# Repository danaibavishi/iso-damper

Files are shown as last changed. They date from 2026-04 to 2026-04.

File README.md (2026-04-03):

**3D Printable · PETG · Open Source · Compliant Mechanism**

# Vibration Isolation Damper for Bookshelf Speakers

Stop your speaker from vibrating your shelf. Built around a real BYU orthoplanar spring — engineered from scratch in Python, iterated through TinkerCAD, tuned for the Sonos Era 100.

| pucks to print | spring scale | deflection | filament cost | design phases |
| --- | --- | --- | --- | --- |
| 3× | 0.40× | 0.63mm | ~$2 | 4 |

## Why does this exist?

The Sonos Era 100 sits directly on your shelf. At volume, cabinet vibrations travel through the shelf into the wall — and back into the bass as muddy resonance. IsoAcoustics pads fix this but cost $50–100. This builds the same thing for the price of a coffee's worth of PETG.

> The key insight: Vibration travels through rigid contact. Break that path with a compliant spring and it has nowhere to go — that's what an orthoplanar spring does.

## The final design

### Print this file — 3 copies
`04_compliant_puck/compliant_puck_FINAL.stl`
*One monolithic piece. No assembly, no hardware. Print 3, place in a triangle under the speaker.*

**Outer diameter:** 57.9 mm  
**Total height:** 24.5 mm  
**Spring arms:** 3× BYU radial legs — 2.0mm wide × 1.52mm thick  
**Arm angles:** 38° / 158° / 278° — matched from BYU STL  
**Deflection:** 0.63mm under 733g load  
**Max stress:** 45 MPa — just under PETG yield (~50 MPa)  
**Pedestal:** 10mm hollow cylinder + 7mm hemisphere dome base  
**Top surface:** 1mm flat solid disc  

*Figure 1 — Compliant puck cross-section · monolithic PETG print*

## Finding the right scale

The BYU spring is 144.8mm across — too large for 3 to fit under the speaker. Scale it down too far and the arms snap. The constraint: 0.2mm layers means arms need at least 1.2mm thickness, setting the minimum spring size.

*Figure 2 — BYU spring anatomy and scale selection*

## How we got here

Four phases, multiple iterations each — every version fixing something the last one got wrong.

1. **Isolation pad** — Simple nub-footed pads. Added BYU spring mechanism. Two versions before realising the spring needed to be structural, not decorative.
2. **Two-piece stand** — Inspired by iRetroLab crystal stands. Tapered pedestal + oval cylinder, spring sandwiched between. Three iterations fixed the connection geometry.
3. **Unified puck** — One monolithic print. Ten iterations: tapered → hollow → domed pedestal. Spring tuned to 0.40× BYU scale.
4. **Tray** — Six iterations. Final: 2mm oval plate (120×130.5mm), 3 pucks embedded below, 1mm raised border to register the speaker.

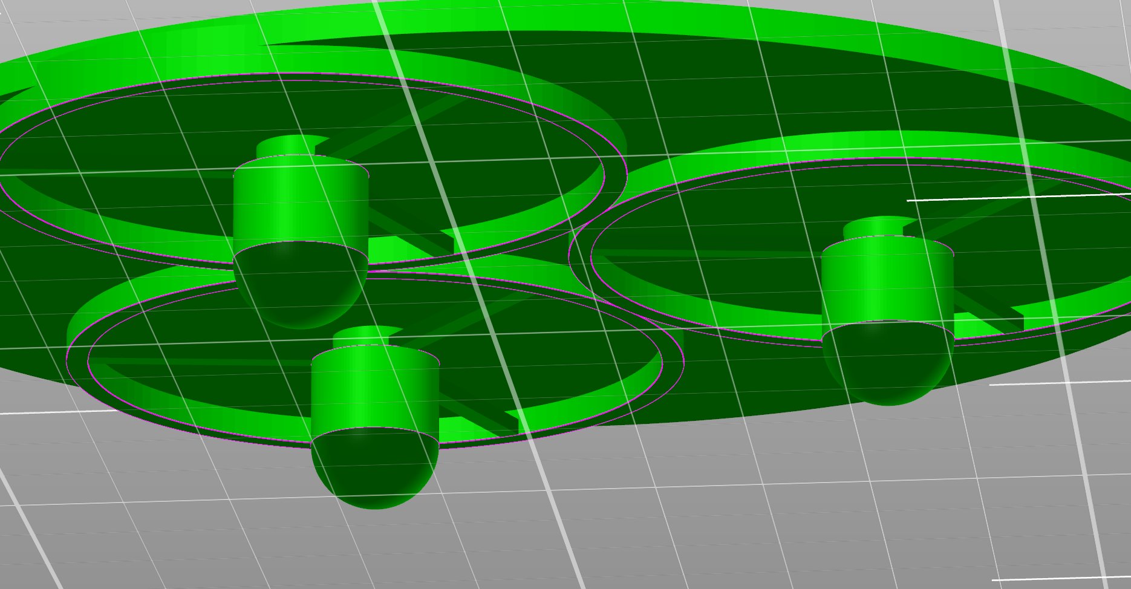
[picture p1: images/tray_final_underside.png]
Final tray — underside showing 3 pucks with dome feet


## The engineering

Each arm is a fixed-guided beam — both ends locked, loaded vertically. Two equations govern everything:

```
δ = F·L³ / (12·E·I) // deflection under load
σ = 6·F·L / (w·t²) // max stress at fixed ends
```

At 0.40× with PETG (E = 1700 MPa): each arm carries 2.4N, deflects 0.63mm — just under the 50 MPa yield point.

> Why 0.40× and not smaller? Below 0.35× the arms exceed PETG yield — permanent deformation. 0.40× is the minimum viable scale at standard 0.2mm layer settings.

## What's in the repo

```
01_concept/           BYU spring STL + anatomy diagram
02_isolation_pad/     nub pad → compliant isolator iterations
03_stand_two_piece/   pedestal + cylinder tray · SCADs
04_compliant_puck/
  compliant_puck_FINAL.stl  ← print this × 3
  iterations/                  v1–v7 intermediate designs
05_tray/
  tray_FINAL.stl              ← oval plate + 3 embedded pucks
  iterations/                  tray v1–v5 exploration
docs/                 engineering_notes.md
images/               all TinkerCAD + slicer screenshots
```

## References

- **BYU Compliant Mechanisms Research Group** — Source of the orthoplanar spring design and STL files
- **Parise, Howell, Magleby** — *Ortho-Planar Linear-Motion Springs*, Mechanism and Machine Theory, Vol. 36, 2001
- **US Patent 6,983,924** — Compliant Ortho-Planar Linear Motion Spring
- **IsoAcoustics** — Commercial isolation reference — same principle, $50–100 price point
- **iRetroLab crystal stand** — Aesthetic inspiration — visible spring mechanism

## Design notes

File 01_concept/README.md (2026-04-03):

**Concept · BYU Research**

# 01 — The Orthoplanar Spring

Everything starts here. A flat spring that deflects vertically — manufactured as a single piece with no assembly required.

## What is an orthoplanar spring?

An orthoplanar spring is a flat, planar mechanism that deflects out of plane (vertically) under load. Unlike a coil spring, it doesn't rotate as it deflects, can be printed as a single flat piece, and has predictable, tuneable stiffness based on arm geometry.

> BYU source: This design comes from the Compliant Mechanisms Research Group at Brigham Young University, led by Prof. Larry Howell. Their STL is the foundation for everything in this project.

*BYU orthoplanar spring — top-down anatomy · 144.78mm diameter*

## Geometry (reverse-engineered from STL)

**Outer diameter:** 144.78 mm  
**Height:** 3.81 mm  
**Centre hub radius:** ~10 mm  
**Outer ring:** r 64–72.4mm (8.4mm wide)  
**Number of arms:** 3 straight radial beams  
**Arm angular positions:** 38° / 158° / 278°  
**Arm width at r=40mm:** ~5 mm  
**Arm region:** r 21.9mm to 58.5mm  

> Why 38° offset? The arms are at 38°/158°/278° — not 0°/120°/240°. This offset prevents alignment with the primary loading axes, distributing stress more evenly across all three arms.

## How it works

The centre hub is the fixed ground — it connects to the pedestal which sits on the shelf. The outer ring is the floating platform — it connects to the cylinder that holds the speaker. The three arms bridge between them, flexing vertically under load.

```
Load applied to outer ring → arms flex in Z direction
Outer ring displaces ±0.63mm relative to fixed hub
Vibration energy absorbed → not transmitted to shelf
```

## Files in this folder

byu_orthoplanar_spring.stl
← original BYU geometry, used as reference throughout

The original spring is 144.8mm in diameter. We scale it to 0.40× (57.9mm OD) for use in the puck — see 04_compliant_puck for full scale analysis.

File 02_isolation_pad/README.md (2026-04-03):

**Phase 1 · First Iteration**

# 02 — Isolation Pad

The first attempt. Simple pads that evolved into proper spring mechanisms — before we realised the spring needed to be structural, not decorative.

## The idea

Start simple: flat pads with small nub feet to create a standoff between speaker and shelf. Minimal contact area = less vibration transmission. Then add a spring inside to get real compliance.

Early pad iteration — tapered pedestal form in TinkerCAD

## Iterations

### v1 — Nub pad

Flat rectangular pad (122×132.5mm). Four tapered nubs on the underside create a standoff. No spring mechanism — pure decoupling through minimal contact area.

> Problem: Nubs reduce contact area but don't provide compliance. The speaker still transmits vibration directly through the rigid pad body.

### v2 — Compliant isolator v1

Added an orthoplanar spring mechanism inside the pad. Three curved arms connecting a centre hub to an outer ring.

> Problem: The arm geometry was disconnected — inner plate floated with no structural connection to the outer ring.

### v3 — Compliant isolator v2

Fixed the arm connections. Hub properly bridges to outer ring. This version works mechanically but the flat disc form factor doesn't provide enough vertical clearance for spring travel.

> Key learning: A flat pad is too low-profile. The spring needs height — the deflection path requires vertical clearance below the speaker. This realisation drove the two-piece stand concept.

## Files in this folder

isolation_pad_v1.stl
nub pad — no spring
isolation_pad_v1.scad
OpenSCAD source
compliant_isolator_v2.stl
fixed spring geometry

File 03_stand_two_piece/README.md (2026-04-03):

**Phase 2 · Press-fit Assembly**

# 03 — Two-Piece Stand

Inspired by iRetroLab crystal glass stands — a visible spring mechanism sandwiched between two press-fit pieces. Three pedestal iterations to get the geometry right.

| pieces | pedestal versions | press-fit clearance |
| --- | --- | --- |
| --- | --- | --- |
| 2 | 3 | 0.2mm |

## Assembly concept

Piece 1 (pedestal) press-fits into the spring centre hub from below. Piece 2 (cylinder + tray) grips the spring outer ring from above. The spring floats between them — no glue, no hardware.

Two-piece stand — disconnected in TinkerCAD showing the separate components

> Design reference: iRetroLab crystal stands use a similar principle — a transparent column with visible spring mechanism, aluminium tray on top, conical base below.

## Pedestal iterations

- **[v1 — rejected]** — **Hollow tapered cone + base ring** — Centre hub disconnected from cone walls — visible gap.
- **[v2 — better]** — **Solid top cap added** — Bridges walls to hub. Base ring still present.
- **[v3 — final]** — **Base ring removed** — Cone sits directly on shelf. Clean minimal form.

### Cylinder tray — 3 versions

- **[v1 — too deep]** — **18mm collar** — Much longer than spring height — wastes material.
- **[v2 — better]** — **10mm collar** — Matched to spring height + small overlap.
- **[v3 — final]** — **Spring height + 2mm** — 0.2mm press-fit clearance. Tight and clean.

## Why we moved on

The oval speaker footprint vs circular spring created a shape mismatch. Making the spring oval requires non-uniform scaling (82.9% X, 90.1% Y) which distorts the arm geometry unevenly — different stiffness on each arm, uneven load distribution.

> Solution: Collapse both pieces into a single monolithic print with the spring geometry built in at the correct scale from the start — no oval distortion needed.

## Files in this folder

pedestal_FINAL.stl
piece 1 — tapered cone, final version
cylinder_tray_FINAL.stl
piece 2 — oval cylinder + tray
piece1_pedestal.scad
OpenSCAD source for pedestal
piece2_cylinder_tray.scad
OpenSCAD source for cylinder tray

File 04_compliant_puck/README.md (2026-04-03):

**Phase 04 · Final Design · 7 Iterations · Print 3x**

# Compliant Puck

The final design. One monolithic print — pedestal, spring, and cylinder in a single piece. Seven iterations refined the geometry until every element was proportional, printable, and functional.

### Print this file — 3 copies
`compliant_puck_FINAL.stl`
*One piece. No assembly, no hardware. Print 3, place in a triangle under the speaker.*

## Final specifications

**Outer diameter:** 57.9 mm  
**Total height:** 24.5 mm  
**Spring arms:** 3x BYU radial — 2.0mm wide x 1.52mm thick at 38/158/278 deg  
**Deflection:** 0.63mm under 733g  
**Max stress:** 45 MPa — PETG yield ~50 MPa  
**Pedestal:** 10mm hollow cylinder + 7mm hemisphere dome  

*Figure 4.1 — Final puck cross-section*

## The iteration journey

From wide-cone tapered base to clean cylinder-plus-dome. Each screenshot marks a decision point.

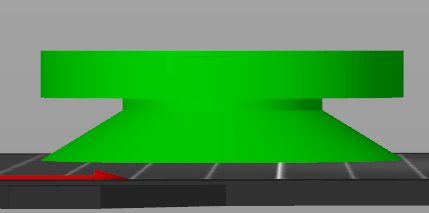
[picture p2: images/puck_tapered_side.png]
Tapered pedestal


v1-v3 — tapered cone — too wide

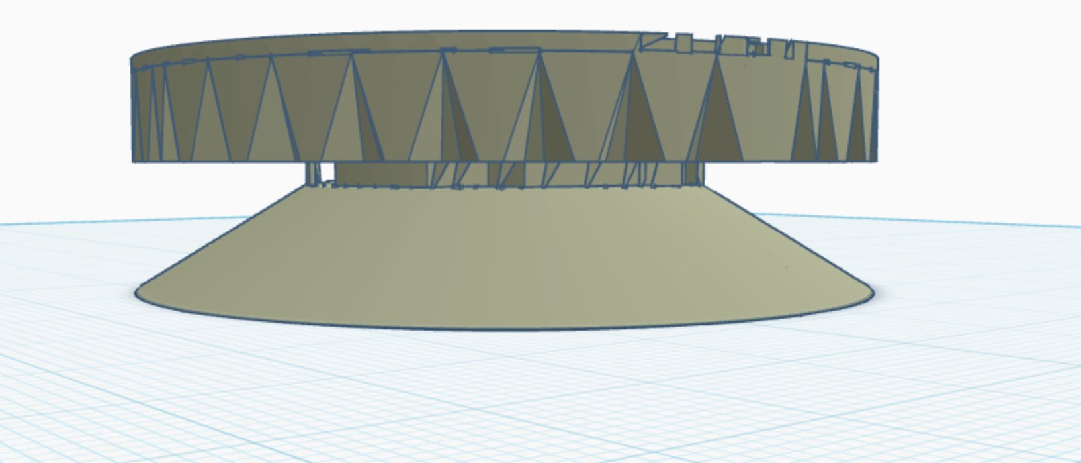
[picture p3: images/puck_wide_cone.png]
Wide cone version


v4 — full-size BYU spring — too large

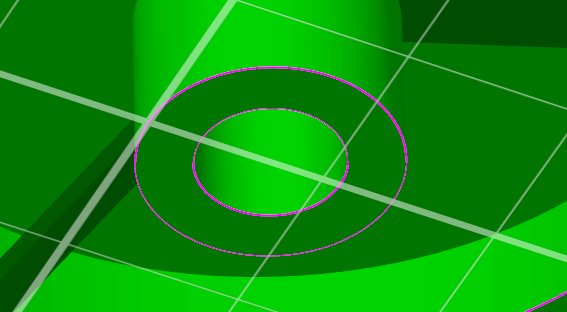
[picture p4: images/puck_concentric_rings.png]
Concentric rings top view


Breakthrough — top-down concentric rings confirmed correct spring geometry at 0.40x scale

> This view locked the design. Seeing hub, arm region, and outer ring clearly defined in one view confirmed the spring would work. From here the only remaining question was the pedestal shape.

## Full iteration log

| Version | Change | Outcome |
| --- | --- | --- |
| v1_initial | Curved spiral arms | Wrong arm style — not BYU geometry |
| v2_40pct | BYU straight arms at 0.40x | Arms correct, geometry locked |
| v3_straight_pedestal | Hollow straight cylinder pedestal | Taper removed — cleaner |
| v4_spike | Spike tip at base | Wrong — spike too narrow |
| v5_dome | Hemisphere dome on full-width base | Dome too tall — disproportionate |
| FINAL | 7mm dome + 10mm straight cylinder | Correct geometry — clean and printable |

## Spring mechanics

```
delta = F x L^3 / (12 x E x I) // deflection = 0.63mm
sigma = 6 x F x L / (w x t^2) // max stress = 45 MPa
```

| Scale | OD | Arm w x t | Deflection | Stress | Valid |
| --- | --- | --- | --- | --- | --- |
| 0.20x | 29mm | 1.0x0.76mm | 1.25mm | 181 MPa | over yield |
| 0.35x | 51mm | 1.8x1.33mm | 0.71mm | 59 MPa | marginal |
| 0.40x | 58mm | 2.0x1.52mm | 0.63mm | 45 MPa | sweet spot |
| 0.50x | 72mm | 2.5x1.91mm | 0.50mm | 29 MPa | safe |

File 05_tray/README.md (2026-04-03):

**Phase 05 · 6 Iterations · Optional Add-on**

# The Tray

An optional oval plate that holds all 3 pucks in the correct triangle layout and registers the speaker with a 1mm raised border. Six iterations to get the geometry right.

## What the tray does

Without a tray you place the 3 pucks manually in a triangle. The tray fuses them into one piece, sized to the Era 100 base (120x130.5mm), with a 1mm lip that stops the speaker sliding.

> The tray is optional. The 3 pucks work perfectly on their own. The tray is useful for a single registered piece that keeps puck positions fixed.

*Figure 5.1 — Tray layout and cross-section with Z levels*

## The iteration journey

Six versions across three approaches — wireframe, oval ring, and flat plate — before landing on the right geometry.

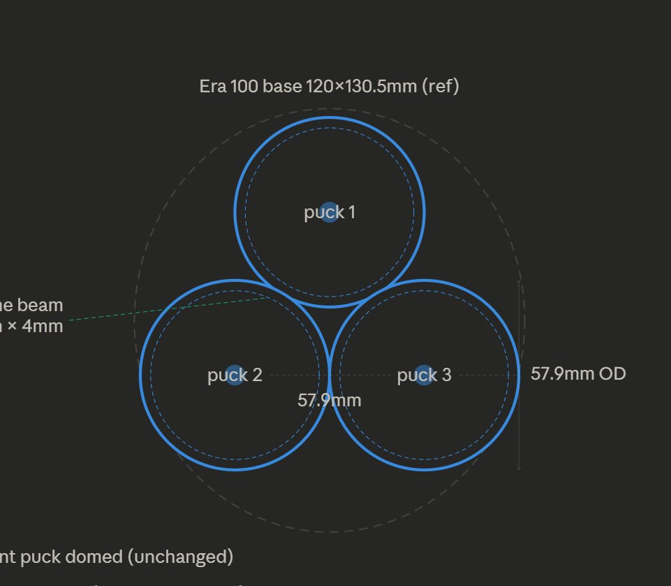
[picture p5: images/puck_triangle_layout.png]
Puck triangle layout


The puck triangle layout — 3 pucks mutually tangent at 57.9mm OD, circumradius 33.4mm

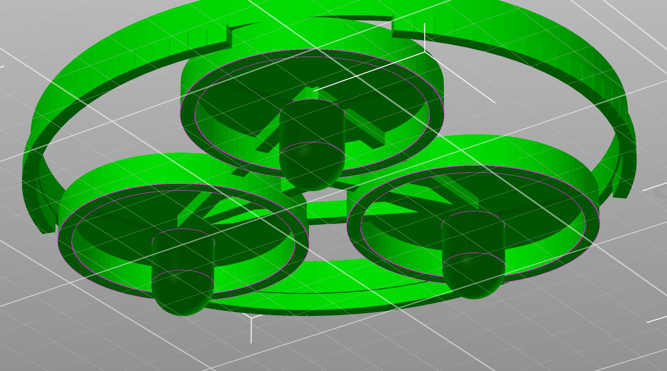
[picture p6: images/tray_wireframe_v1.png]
First wireframe


v1 — heavy outer ring and cross ribs — arms miss springs

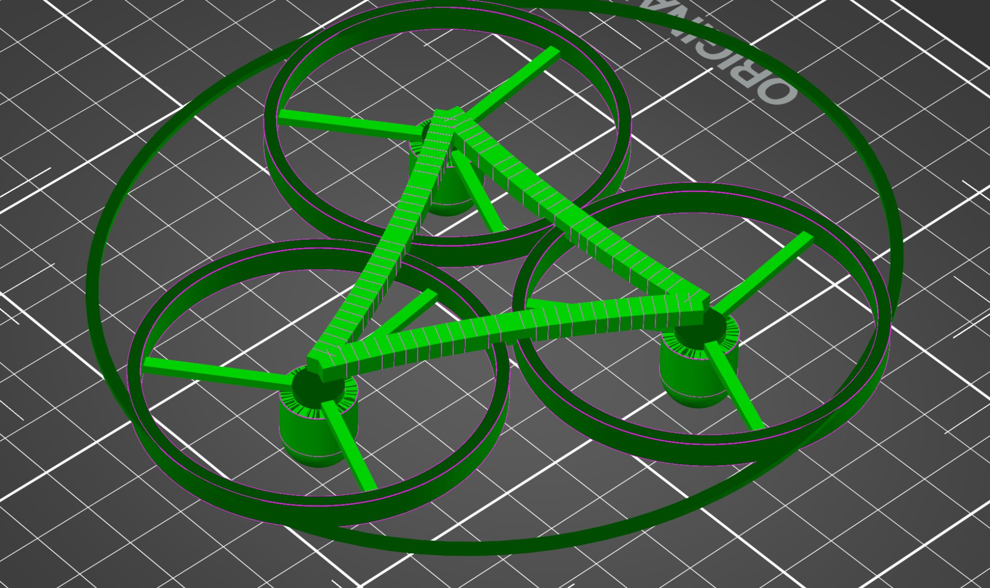
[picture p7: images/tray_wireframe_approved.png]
Cleaner wireframe


v3 — cleaner wireframe oval ring — better direction

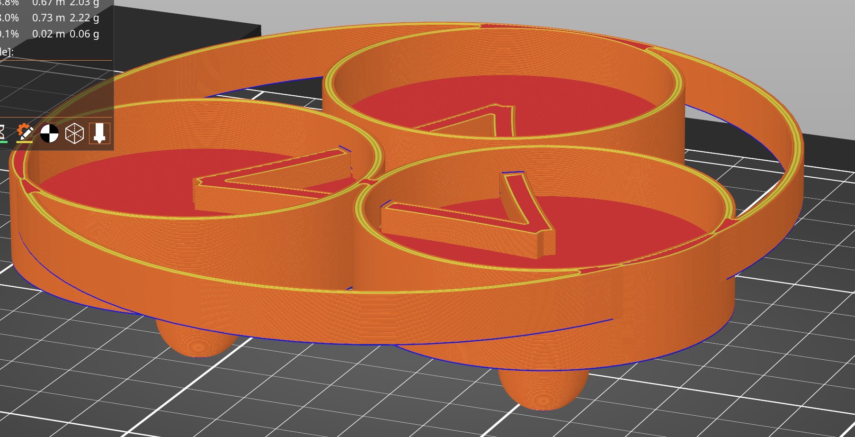
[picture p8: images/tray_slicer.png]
Tray in slicer


Slicer preview — pucks sliced with spring arms visible from below

Final tray underside

Final tray — underside showing 3 domed pucks embedded below the 2mm oval plate

> The fix that cracked it: All puck geometry strictly below z=0. The plate is z=0 to +2mm. Puck rings, springs, pedestals and domes are z=0 to -16.5mm. Keeping zones separated fixed the pedestal-through-plate bug.

## Iteration log

| Version | Design approach | Problem |
| --- | --- | --- |
| tray_v1 | Wireframe — 3 curved arms + heavy outer ring | Arms miss springs |
| tray_v2 | Open top pucks, thin ring wall | Arms protrude as propeller blades |
| tray_v3 | Thin oval ring shell fused to puck rings | Cleaner but arms still exposed |
| tray_v4 | 2mm flat oval plate, pucks below | Pedestal poked above plate — Z bug |
| tray_v5 | v4 + 1mm raised lip border | Same Z bug persisted |
| tray_FINAL | All geometry strictly below z=0 | Correct — clean underside |

## Z level breakdown

| Level | Description |
| --- | --- |
| `z = +3.0mm` | top of 1mm raised lip |
| `z = +2.0mm` | top of oval plate — speaker sits here |
| `z = 0.0mm` | bottom of plate / top of puck rings |
| `z = -2.52mm` | bottom of spring zone |
| `z = -10.52mm` | bottom of pedestal |
| `z = -16.52mm` | dome tip — shelf contact point |

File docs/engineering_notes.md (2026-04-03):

# Engineering Notes

## Acoustic isolation principles

Speaker cabinets vibrate at the frequencies they reproduce. Vibration transmits through rigid shelf contact, re-radiating as coloured bass and low-frequency energy through walls. Two mechanisms break the path:

1. **Compliance** — a flexible interface absorbs vibrational energy rather than transmitting it
2. **Minimal contact area** — dome/spike contact points reduce the surface area for lateral shear wave transmission

This design uses both.

---

## Fixed-guided beam mechanics

Each spring arm behaves as a fixed-guided beam — both ends constrained against rotation, loaded vertically.

```
Deflection:    δ = F·L³ / (12·E·I)
Max stress:    σ = 6·F·L / (w·t²)
Second moment: I = w·t³ / 12
```

**Material — PETG:**

| Property | Value |
|---|---|
| Young's modulus (E) | 1700 MPa |
| Yield strength | ~50 MPa |
| Target safety factor | ≥ 1.1× |

---

## Scale sensitivity

When scaling the BYU spring uniformly by factor S, both δ and σ scale as 1/S. A smaller spring is stiffer but also lower stress. The constraint is printability: arms need ≥ 6 layers at 0.2mm = 1.2mm minimum thickness.

**At 0.40× scale (chosen):**
- Load per arm: 2.2kg ÷ 3 pucks ÷ 3 arms = 2.4N
- Arm length: 72.4mm × 0.40 - hub = 14.6mm
- Arm size: 2.0mm × 1.52mm
- Deflection: **0.63mm** ✓
- Max stress: **45 MPa** (yield margin 1.11×) ✓

---

## BYU spring geometry (reverse-engineered from STL)

```
Outer diameter:         144.78mm
Height:                  3.81mm
Centre hub radius:       ~10mm
Hub ring outer edge:     ~21.9mm
Outer ring inner edge:   ~64mm
Outer ring outer edge:   ~72.4mm
Arm positions:           38°, 158°, 278° (120° spacing, 38° offset)
Arm width at r=40mm:     ~5mm
Arm region:              r = 21.9mm to 58.5mm
```

The 38° offset prevents arms aligning with primary loading axes, distributing stress more evenly.

---

## Non-uniform scaling risk

Scaling the circular spring non-uniformly to fit an oval footprint distorts arm geometry — different stiffness in X vs Y. This is why the design uses a **circular spring at 0.40× uniform scale** placed under an oval plate, rather than stretching the spring to match the oval.

---

## Why PETG over PLA or TPU

| Material | E (MPa) | Yield (MPa) | Notes |
|---|---|---|---|
| PLA | 3500 | 55 | Too stiff — spring barely deflects |
| **PETG** | **1700** | **50** | **Sweet spot** |
| TPU 95A | 30–50 | 8–15 | Too soft — poor dimensional accuracy |

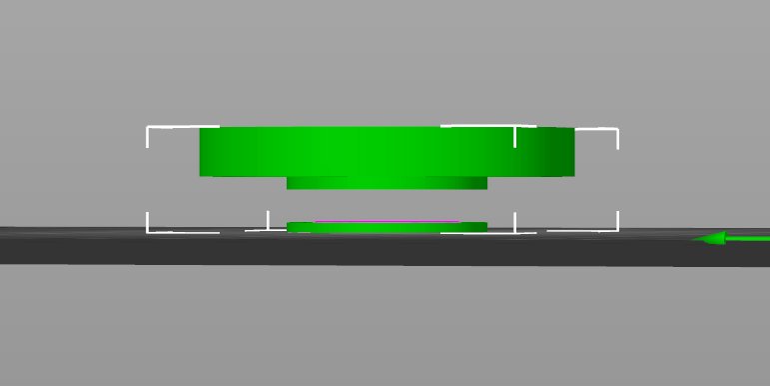
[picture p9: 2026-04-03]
images/stand_disconnected.png

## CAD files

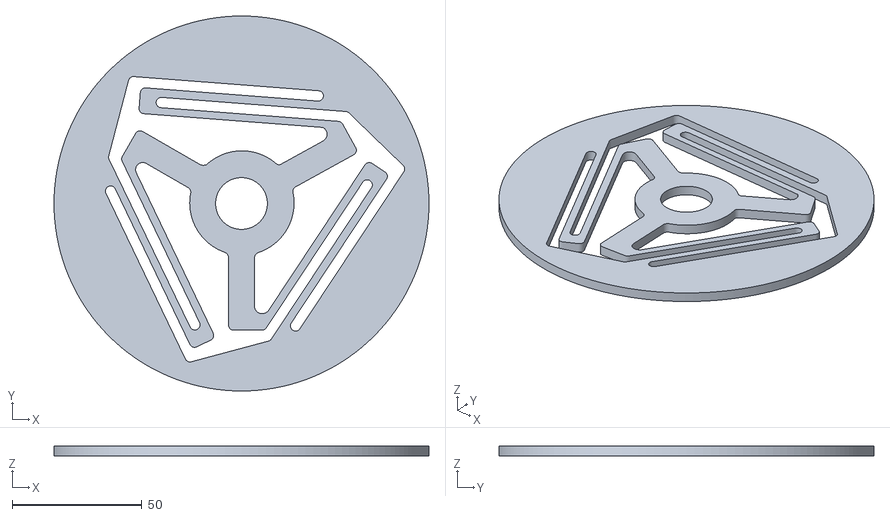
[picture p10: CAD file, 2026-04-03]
01_concept/byu_orthoplanar_spring.stl
144.8 x 144.8 x 3.81

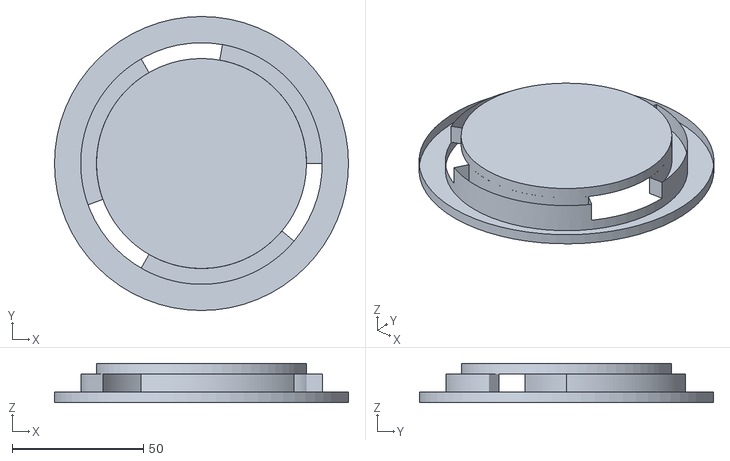
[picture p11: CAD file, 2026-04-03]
02_isolation_pad/compliant_isolator_v2.stl
112.0 x 112.0 x 15.0

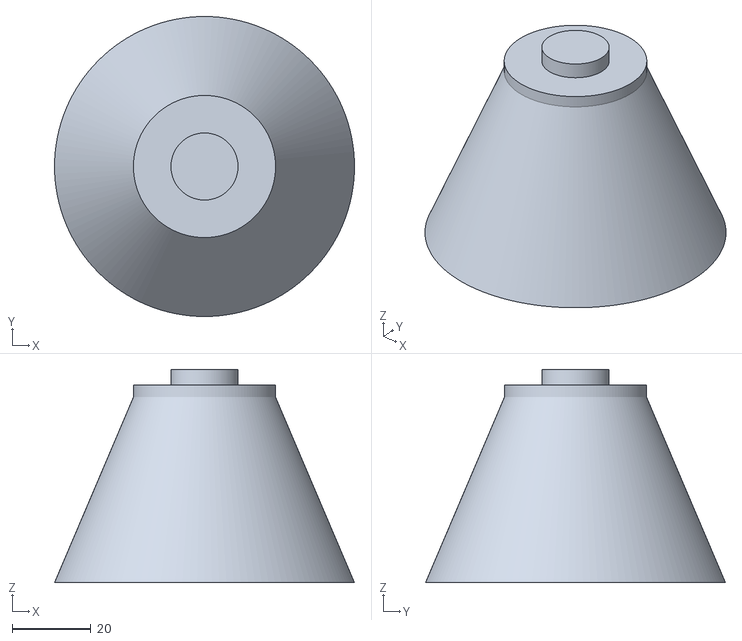
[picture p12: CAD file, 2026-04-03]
03_stand_two_piece/pedestal_FINAL.stl
76.0 x 76.0 x 54.0

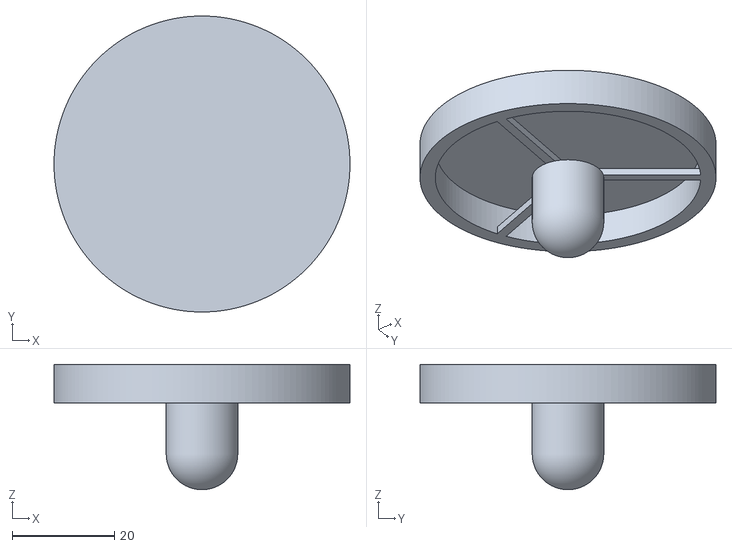
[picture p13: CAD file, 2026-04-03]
04_compliant_puck/compliant_puck_FINAL.stl
57.9 x 57.9 x 24.5

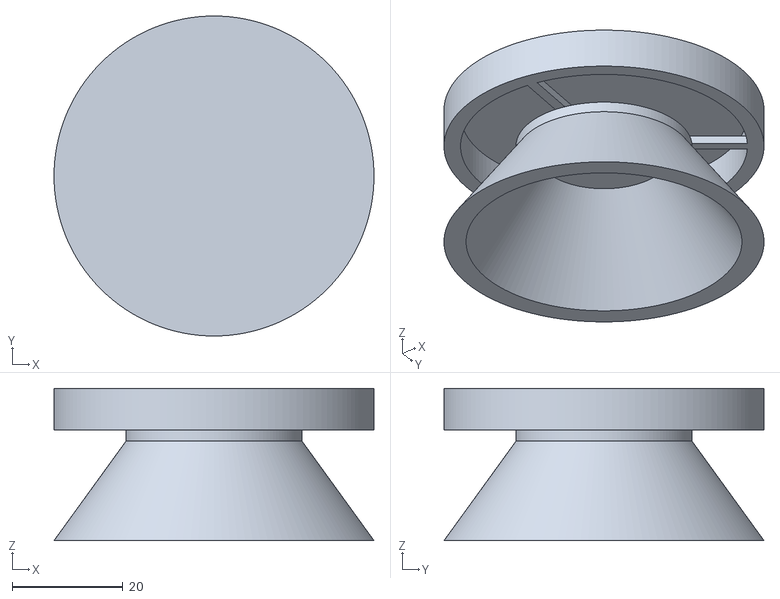
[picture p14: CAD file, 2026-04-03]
04_compliant_puck/iterations/v2_40pct.stl
57.9 x 57.9 x 27.5

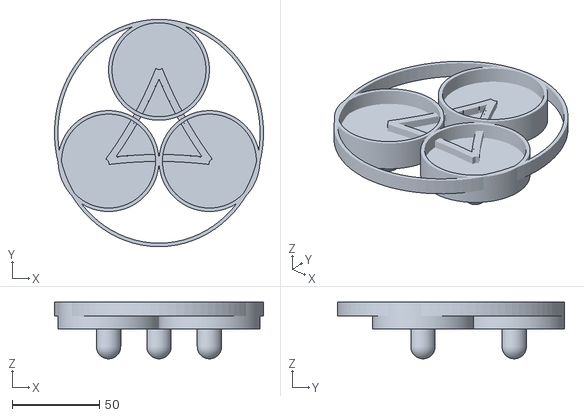
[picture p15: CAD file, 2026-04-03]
05_tray/iterations/tray_v1_wireframe.stl
120.0 x 130.5 x 32.5

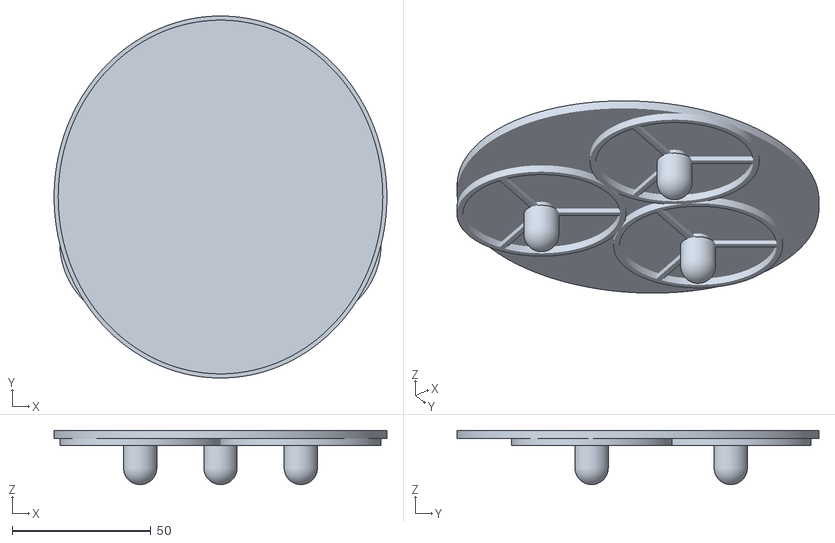
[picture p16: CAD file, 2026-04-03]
05_tray/tray_FINAL.stl
120.0 x 130.5 x 19.5

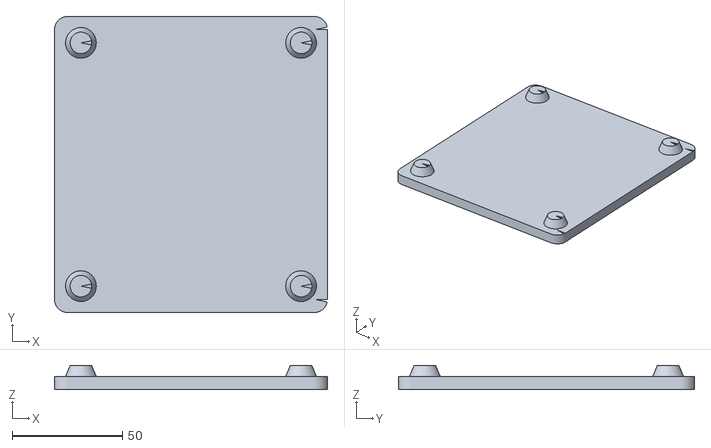
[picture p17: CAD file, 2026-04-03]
02_isolation_pad/isolation_pad_v1.stl
124.0 x 134.5 x 11.0

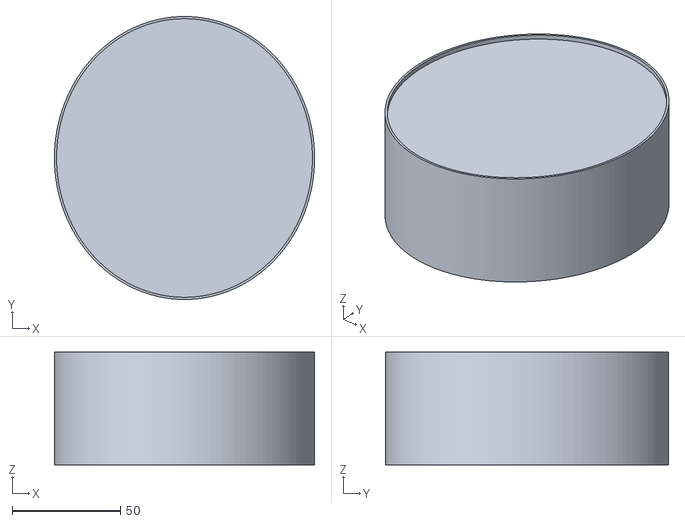
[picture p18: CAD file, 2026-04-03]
03_stand_two_piece/cylinder_tray_FINAL.stl
120.0 x 130.5 x 52.0

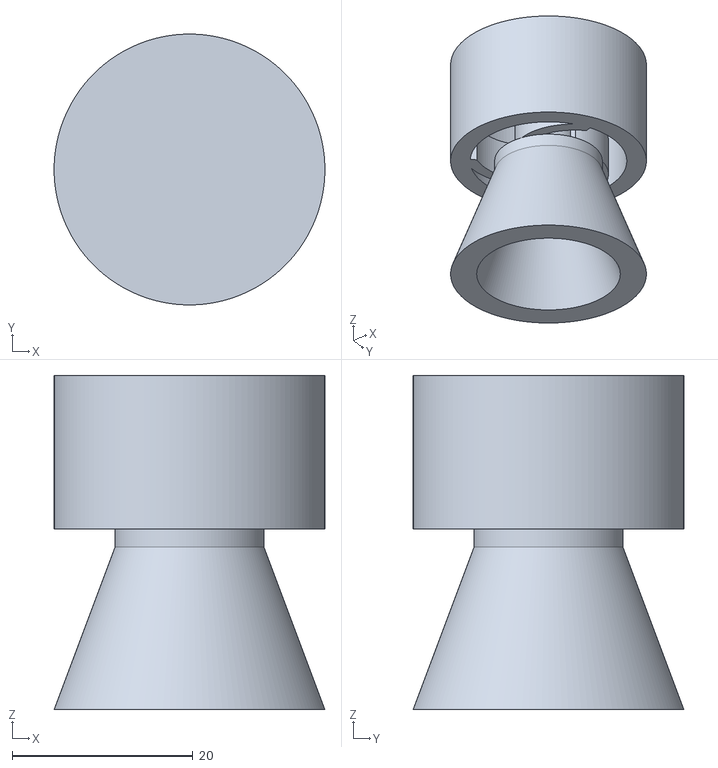
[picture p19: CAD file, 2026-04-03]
04_compliant_puck/iterations/v1_initial.stl
30.0 x 30.0 x 37.0

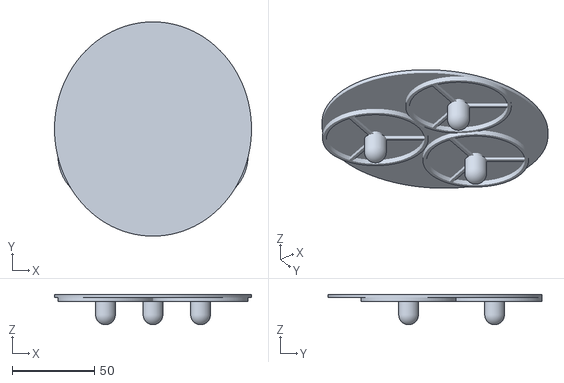
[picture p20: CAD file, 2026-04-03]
05_tray/iterations/tray_v3_flat_plate.stl
120.0 x 130.5 x 18.5

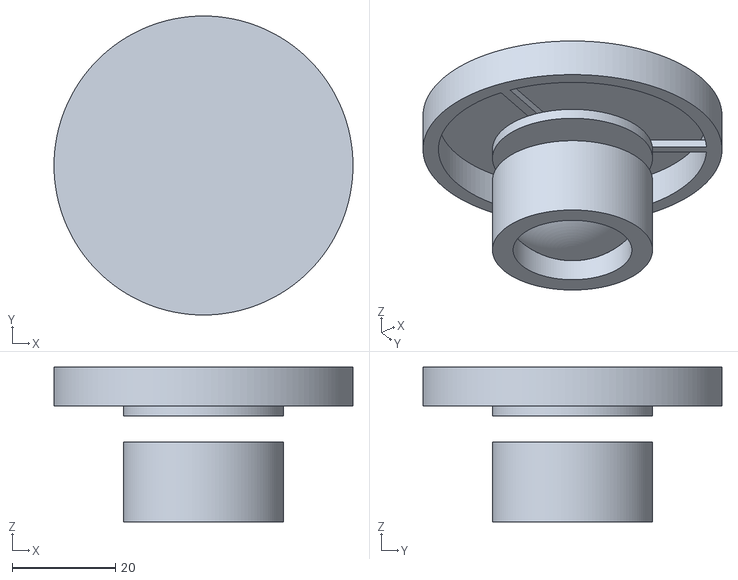
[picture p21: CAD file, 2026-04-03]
04_compliant_puck/iterations/v5_dome.stl
57.9 x 57.9 x 30.0

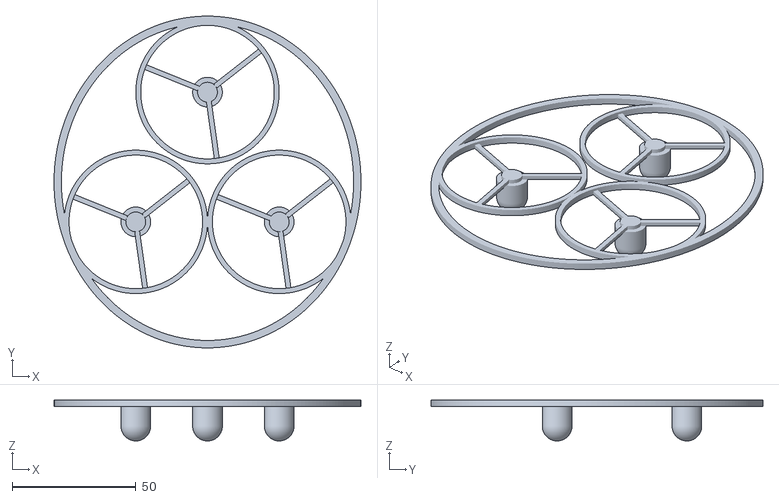
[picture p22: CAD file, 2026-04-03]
05_tray/iterations/tray_v2_oval_ring.stl
124.0 x 134.0 x 16.5

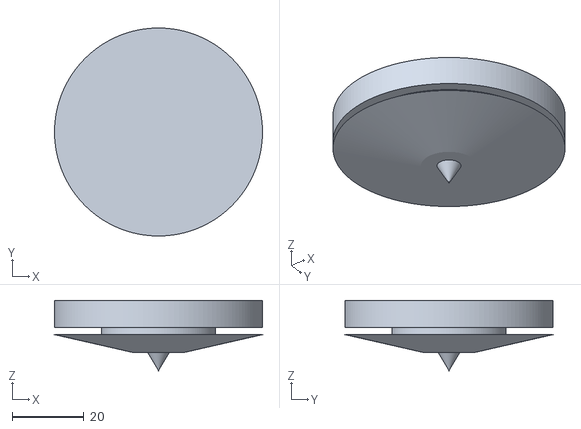
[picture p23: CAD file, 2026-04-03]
04_compliant_puck/iterations/v4_spike.stl
57.9 x 57.9 x 19.5

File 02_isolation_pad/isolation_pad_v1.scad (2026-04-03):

// Sonos Era 100 Isolation Pad
// Material: PETG recommended
// Speaker footprint: 120mm W x 130.5mm D
// Pad adds 2mm margin on each side for easy placement

// --- Parameters ---
pad_width   = 124;   // mm (120 + 2mm margin each side)
pad_depth   = 134.5; // mm (130.5 + 2mm margin each side)
pad_height  = 6;     // mm base thickness

// Nub (isolation foot) parameters
nub_diameter  = 14;  // mm
nub_height    = 5;   // mm
nub_inset     = 12;  // mm from each corner (center of nub)
nub_fn        = 32;  // smoothness

// Corner radius for aesthetics
corner_radius = 6;   // mm

// --- Main Body (rounded rectangle base) ---
module rounded_rect(w, d, h, r) {
    hull() {
        translate([ r,  r, 0]) cylinder(r=r, h=h, $fn=nub_fn);
        translate([w-r, r, 0]) cylinder(r=r, h=h, $fn=nub_fn);
        translate([ r, d-r, 0]) cylinder(r=r, h=h, $fn=nub_fn);
        translate([w-r, d-r, 0]) cylinder(r=r, h=h, $fn=nub_fn);
    }
}

// --- Nub (vibration isolation foot) ---
// Tapered cylinder for better grip and isolation
module nub() {
    cylinder(d1=nub_diameter, d2=nub_diameter*0.7, h=nub_height, $fn=nub_fn);
}

// --- Assemble ---
union() {
    // Base pad
    rounded_rect(pad_width, pad_depth, pad_height, corner_radius);

    // Four corner nubs on the bottom (printed upside down, so they appear on top in model)
    // When printing: orient so nubs face DOWN onto the shelf surface
    translate([nub_inset,            nub_inset,            pad_height]) nub();
    translate([pad_width - nub_inset, nub_inset,            pad_height]) nub();
    translate([nub_inset,            pad_depth - nub_inset, pad_height]) nub();
    translate([pad_width - nub_inset, pad_depth - nub_inset, pad_height]) nub();
}

// --- PRINT NOTES (read before slicing) ---
// 1. Print UPSIDE DOWN (nubs facing the build plate) so nubs face DOWN in use
// 2. PETG settings: 240°C nozzle, 70-80°C bed, 3 walls, 20-30% infill
// 3. No supports needed
// 4. Print 2 copies — one per speaker
// 5. The nubs contact the shelf; the flat top supports the speaker
// 6. Optional: press small rubber O-rings or silicone bumper stickers
//    onto the nub tips for extra damping

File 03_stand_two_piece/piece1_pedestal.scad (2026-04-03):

// ============================================================
//  PIECE 1 — Tapered Hollow Pedestal
//  Sonos Era 100 Isolation Stand
//  Material: PETG — 240°C nozzle, 75°C bed
//  Print upright, no supports needed
// ============================================================

$fn = 128;

// ── Spring interface dimensions (from STL analysis) ──────────
SPRING_HUB_R     = 8.7;    // scaled hub radius (fits into spring centre)
PIN_R            = SPRING_HUB_R - 0.2;  // 0.2mm press-fit clearance
PIN_H            = 4.0;    // pin height that inserts into spring hub

// ── Pedestal body ─────────────────────────────────────────────
PED_H            = 50.0;   // 5cm tall
PED_R_TOP        = 18.0;   // narrow top (near spring)
PED_R_BOT        = 38.0;   // wide base
WALL             = 8.0;    // 8mm thick walls (hollow cone)

// ── Base disc ─────────────────────────────────────────────────
BASE_R           = PED_R_BOT + 6.0;  // slightly wider than cone base
BASE_H           = 3.0;

// ── Assembly ──────────────────────────────────────────────────
union() {

    // 1. Base disc — sits on shelf
    cylinder(r=BASE_R, h=BASE_H);

    // 2. Hollow tapered cone
    //    Outer cone minus inner (offset by WALL)
    difference() {
        // Outer cone
        translate([0, 0, BASE_H])
            cylinder(r1=PED_R_BOT, r2=PED_R_TOP, h=PED_H);

        // Inner hollow — same taper, wall inset by WALL
        translate([0, 0, BASE_H - 0.01])
            cylinder(
                r1 = PED_R_BOT - WALL,
                r2 = max(PED_R_TOP - WALL, 2.0),
                h  = PED_H + 0.02
            );
    }

    // 3. Press-fit pin at top — inserts into spring centre hub
    translate([0, 0, BASE_H + PED_H])
        cylinder(r=PIN_R, h=PIN_H);
}

// ── PRINT NOTES ───────────────────────────────────────────────
// Orientation : upright (base on build plate)
// Supports    : none needed
// Infill      : 20% gyroid for base disc, walls are solid by geometry
// PETG        : 240°C / 75°C bed / 3 perimeters
// After print : press pin up into spring centre hub

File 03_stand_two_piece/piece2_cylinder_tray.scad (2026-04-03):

// ============================================================
//  PIECE 2 — Oval Cylinder + Tray
//  Sonos Era 100 Isolation Stand
//  Material: PETG — 240°C nozzle, 75°C bed
//  Print upside-down (tray face on build plate), no supports
// ============================================================

$fn = 128;

// ── Speaker base footprint (Era 100) ─────────────────────────
SPK_W            = 120.0;   // width
SPK_D            = 130.5;   // depth

// ── Oval cylinder dimensions ──────────────────────────────────
// Outer ellipse matches speaker base exactly
CYL_A            = SPK_W / 2;        // semi-axis X = 60mm
CYL_B            = SPK_D / 2;        // semi-axis Y = 65.25mm
CYL_WALL         = 5.0;              // 5mm wall thickness
CYL_H            = 30.0;             // 3cm tall

// Inner ellipse (hollow interior)
CYL_A_IN         = CYL_A - CYL_WALL;
CYL_B_IN         = CYL_B - CYL_WALL;

// ── Tray plate ────────────────────────────────────────────────
TRAY_THICK       = 2.0;    // 2mm flat top plate
LIP_H            = 2.0;    // raised lip height
LIP_T            = 1.0;    // lip thickness

// ── Spring outer ring interface (press-fit collar) ────────────
// Outer ring of scaled spring: inner r ~53mm oval, outer r ~60/65mm
// Collar sits at bottom of cylinder, grips spring outer ring
COLLAR_H         = 5.0;    // how deep the collar grips the spring
COLLAR_EXTRA     = 1.5;    // collar is slightly thicker for grip

// ── Scaled spring reference (for sizing collar) ───────────────
// Original spring outer ring: r 64–72.4mm circular
// Scaled to oval 120x130.5: outer edge IS the cylinder outer wall
// Collar inner matches spring outer ring inner edge
COLLAR_A_IN      = CYL_A_IN - COLLAR_EXTRA;
COLLAR_B_IN      = CYL_B_IN - COLLAR_EXTRA;

// ── Helper: oval prism via scale on cylinder ──────────────────
module oval_solid(a, b, h) {
    scale([1, b/a, 1]) cylinder(r=a, h=h);
}

module oval_shell(a_out, b_out, a_in, b_in, h) {
    difference() {
        oval_solid(a_out, b_out, h);
        translate([0, 0, -0.01])
            oval_solid(a_in, b_in, h + 0.02);
    }
}

// ── Tray Z reference ──────────────────────────────────────────
// Tray plate at top: z = CYL_H to CYL_H + TRAY_THICK
// Lip above that:    z = CYL_H + TRAY_THICK to CYL_H + TRAY_THICK + LIP_H

union() {

    // 1. Oval cylinder walls
    oval_shell(CYL_A, CYL_B, CYL_A_IN, CYL_B_IN, CYL_H);

    // 2. Thickened press-fit collar at bottom (grips spring outer ring)
    oval_shell(CYL_A, CYL_B, COLLAR_A_IN, COLLAR_B_IN, COLLAR_H);

    // 3. Tray top plate — solid oval disc
    translate([0, 0, CYL_H])
        oval_solid(CYL_A, CYL_B, TRAY_THICK);

    // 4. Raised perimeter lip on tray
    //    Outer lip edge = tray outer edge
    //    Inner lip edge = tray outer - LIP_T
    translate([0, 0, CYL_H + TRAY_THICK])
        oval_shell(
            CYL_A,        CYL_B,
            CYL_A - LIP_T, CYL_B - LIP_T,
            LIP_H
        );
}

// ── PRINT NOTES ───────────────────────────────────────────────
// Orientation : UPSIDE DOWN (tray plate on build plate)
//               This puts the collar at the top during printing
//               and avoids overhangs on the tray underside
// Supports    : none needed in this orientation
// Infill      : 15% gyroid
// PETG        : 240°C / 75°C bed / 3 perimeters
// After print : press collar down over spring outer ring
//               Spring sits inside collar, gripped by friction

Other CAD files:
04_compliant_puck/iterations/v3_straight_pedestal.stl
